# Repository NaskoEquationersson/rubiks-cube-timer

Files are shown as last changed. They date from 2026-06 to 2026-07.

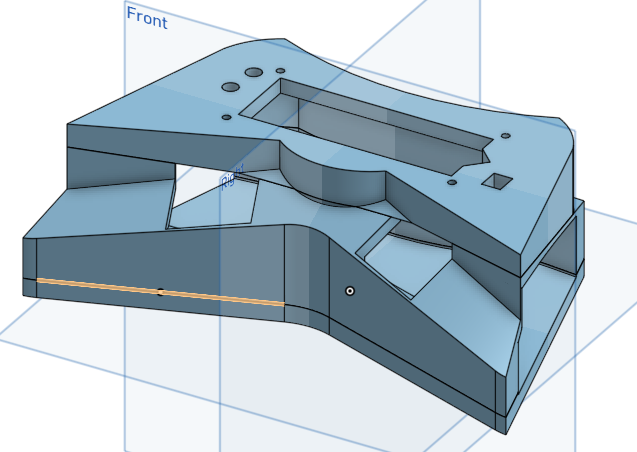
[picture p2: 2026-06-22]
images/Middle.png

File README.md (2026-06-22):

# Nasko's Stasis Rubik's Cube Timer

**Aim**: To make a cheap, reliable timer for my Rubik's Cube runs that includes all the features a standard StackMat provides.

Here is the example circuit design of the project:

newer_circuit

Here is the cover that will be used to contain the Rubik's Cube timer with electronics, without electronics, the Left Hand part, the Right Hand part, and the Middle part:

wElectronics

woElectronics

L

Middle

R

Here is the top case that would be used to communicate with the timer, with and without electronics, from the front and back:

Ekran Görüntüsü 2026-06-22 10-09-04

Ekran Görüntüsü 2026-06-22 10-09-13

Ekran Görüntüsü 2026-06-22 10-28-15

Ekran Görüntüsü 2026-06-22 10-28-27

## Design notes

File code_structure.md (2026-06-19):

# Sections

- Timer Part
- Receiver Display

# Timer Code

Define port numbers.

Define functions that would be used in the code here.

Start

Connect to WiFi, then ESP-NOW.

Define all i/o ports if needed.

Define all variables that would be needed in the code here.

Reset all LEDs to LOW.

While loop to check if the RESET button is not pressed.
Do the RESET function otherwise.

If the RESET button is not pressed, execute the check for the press.

If at least one of the touch sensors are pressed, begin startup sequence.
First set RED_LED to HIGH, then set it LOW, and GREEN_LED to HIGH.
Make sure to do the timing right.

If any point in that code, the reset button is pressed, or no touch sensor is on,
close the loop and close all the lights with the RESET function.

If the sensors are pressed the required time, wait for one of them to be removed, and start the time.

Send this data to the other timer using ESP-NOW.

Wait for all sensors to activate afterwards, after the time starts.
Make sure to accept RESET function anytime.

If all of the sensors are pressed again, stop the time, and send the signal to the remote.

After the time is complete, wait for another entry with either RESET button, or all sensors pressed again.

# Receiver Code

Define port numbers.

Define functions that would be used in the code here.

Start

Connect to WiFi, then ESP-NOW.

Define all i/o ports if needed.

Define all variables that would be needed in the code here.

Receive the data from the other ESP32 via ESP-NOW, and write it on the LCD screen.

If RESET signal comes, empty the LCD.

If FINISH signal comes, open and close the LCD with the time.

Do all of these in a while loop.

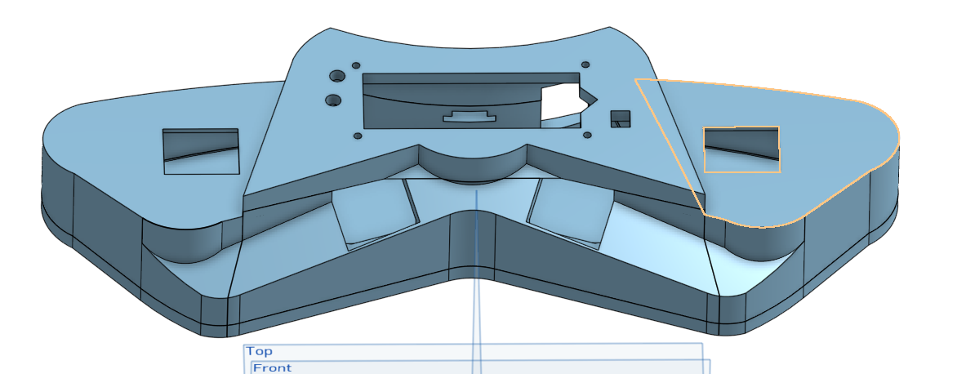
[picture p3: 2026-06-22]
images/woElectronics.png

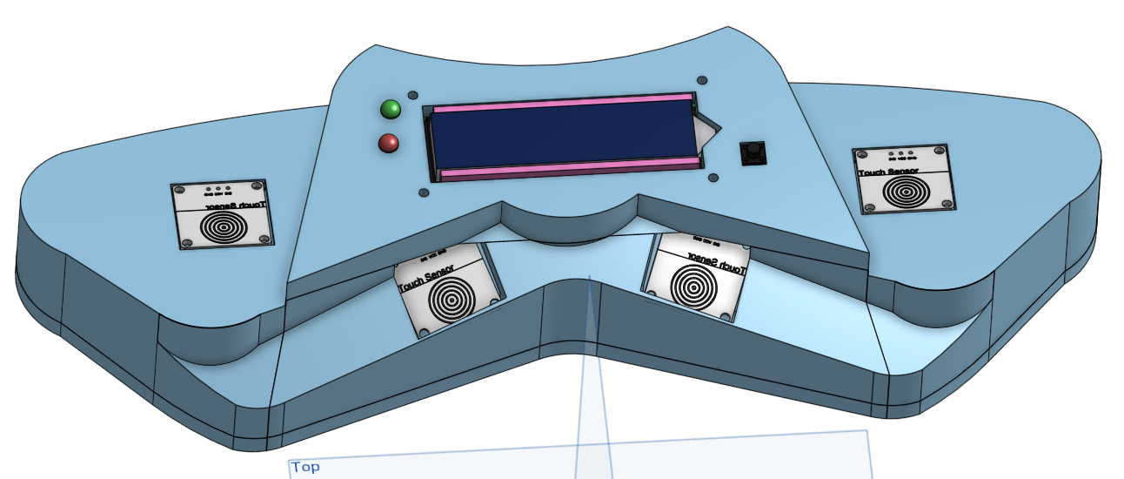
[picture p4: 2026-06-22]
images/wElectronics.png

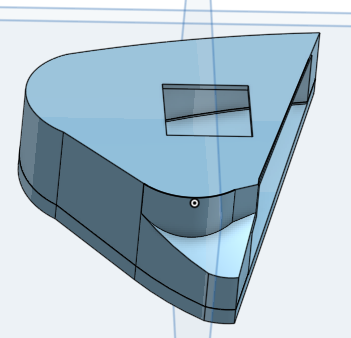
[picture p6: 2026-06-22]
images/L.png

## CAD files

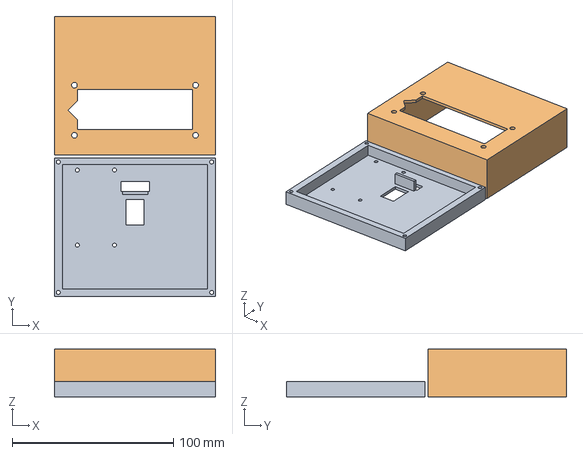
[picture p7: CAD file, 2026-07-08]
final_models/Top_Case.step
100.0 x 173.4 x 29.5 mm

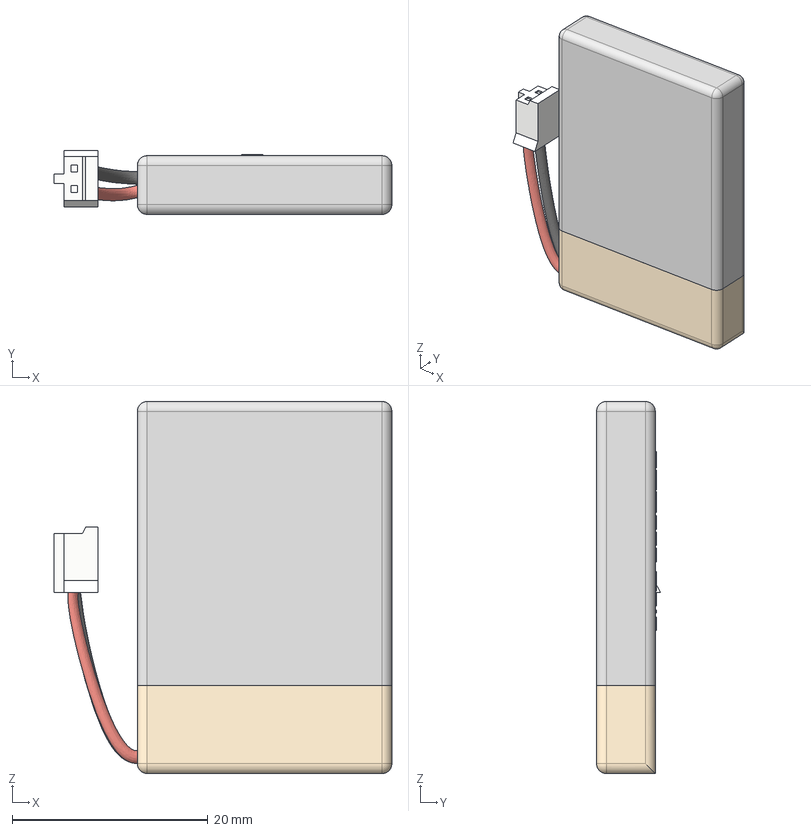
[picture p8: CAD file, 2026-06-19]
models_used_for_scale/3-7v-500mah-lipo-battery-1.snapshot.1/3.3V 500Mah Battery v2.step
34.5 x 6.52 x 38.0 mm
Black wIRE
Red Wire
Connector
Text
Text (1)

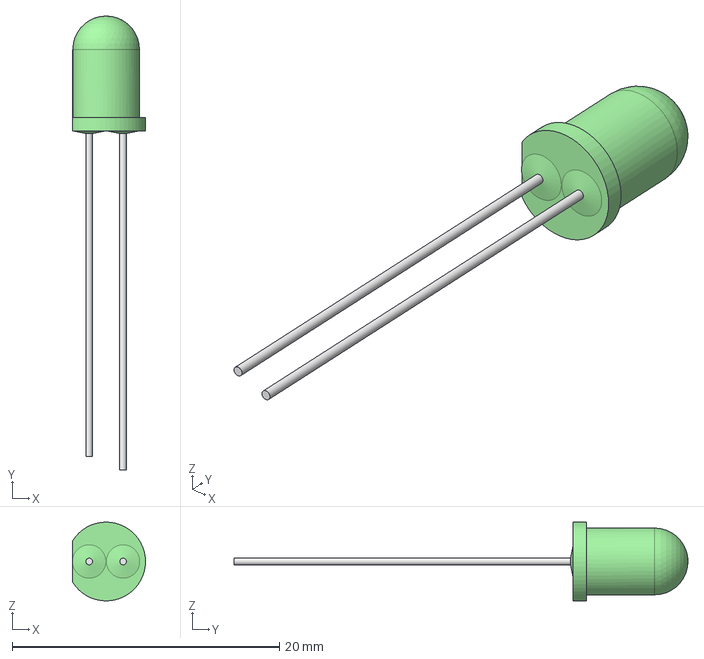
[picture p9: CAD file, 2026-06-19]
models_used_for_scale/5mm-led-green-1.snapshot.1/5mm_LED_Green-0.stp
5.47 x 34.0 x 5.90 mm

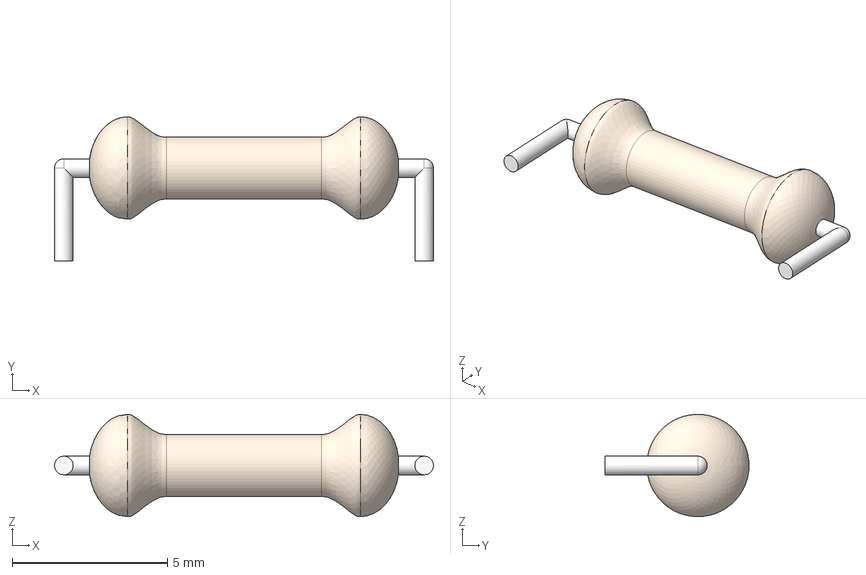
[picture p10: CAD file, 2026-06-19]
models_used_for_scale/generic-1-2w-axial-resistor-1.snapshot.1/1_2W_Axial_res.step
12.2 x 4.65 x 3.30 mm

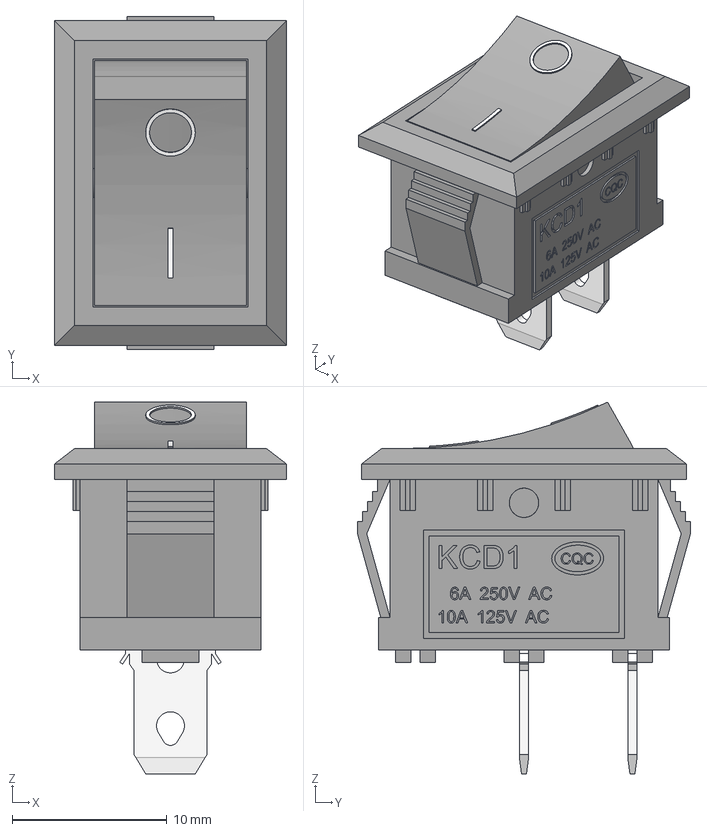
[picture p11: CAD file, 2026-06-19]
models_used_for_scale/kcd1-on-off-rocker-switch-2-pins-1.snapshot.5/kcd1_a.step
15.0 x 21.5 x 24.0 mm
Blade_001
Blade_002
Base_w_text
knob001

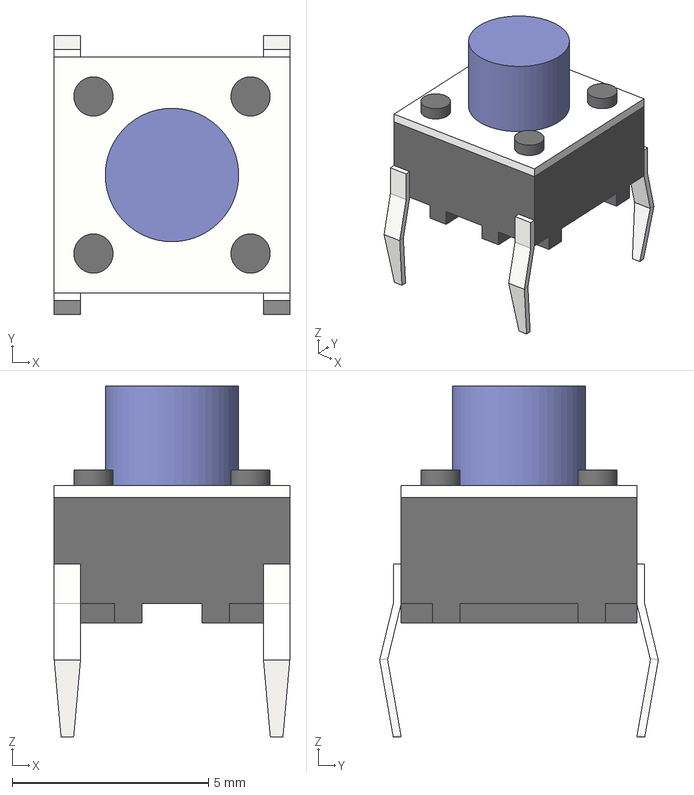
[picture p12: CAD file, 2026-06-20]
models_used_for_scale/micro-momentary-tactile-tact-touch-push-button-switch-6x6x6-mm-1.snapshot.4/Micro Momentary Tactile Tact Touch Push Button Switch, 6x6x6 mm.step
6.00 x 7.10 x 8.94 mm

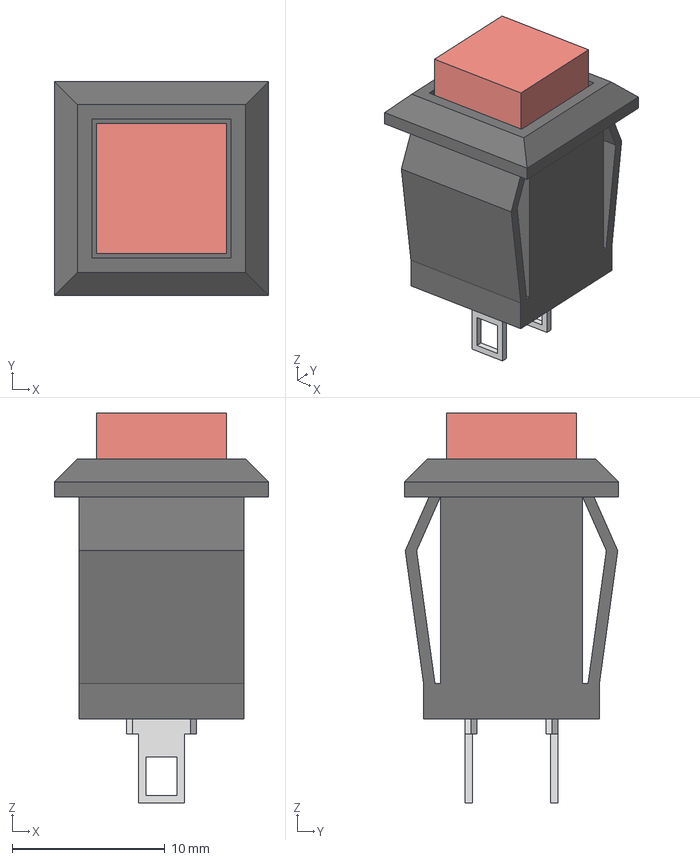
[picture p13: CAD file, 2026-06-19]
models_used_for_scale/square-push-button-ds-431-1.snapshot.13/Square Push Button DS-431 Red.step
14.0 x 14.0 x 25.5 mm

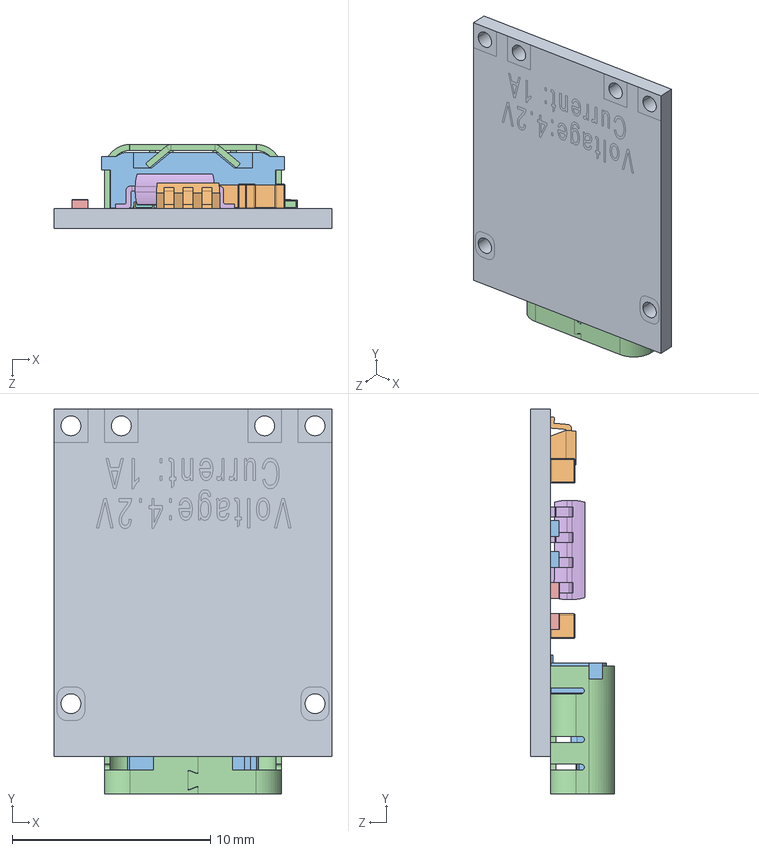
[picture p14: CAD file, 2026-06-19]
models_used_for_scale/tp4056-mini-type-c-battery-charging-module-1.snapshot.1/TP4056 Mini.STEP
14.0 x 19.4 x 4.24 mm

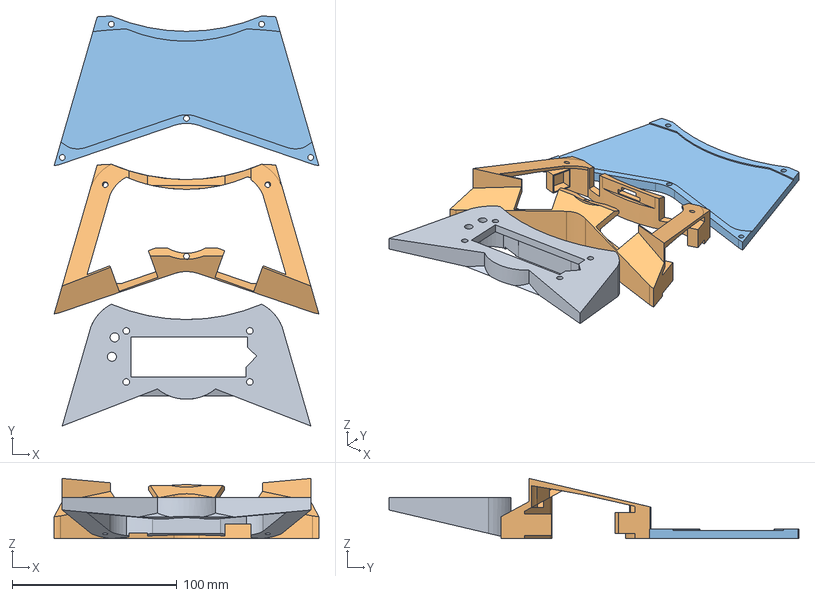
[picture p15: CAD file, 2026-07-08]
final_models/Base.step
160.8 x 249.0 x 36.6 mm

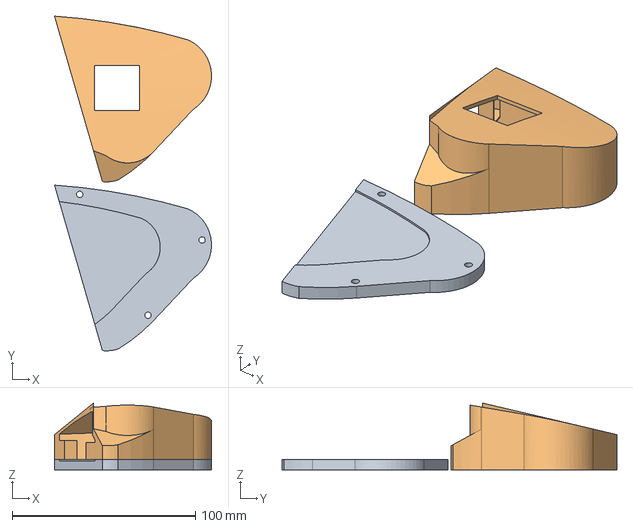
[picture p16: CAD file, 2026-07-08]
final_models/R Hand.step
85.7 x 182.8 x 36.6 mm

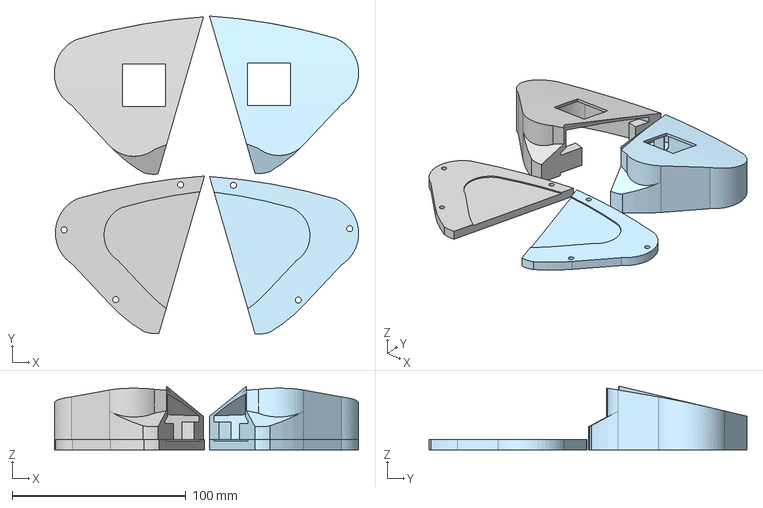
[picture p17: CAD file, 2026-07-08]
final_models/R and L.step
175.0 x 182.8 x 36.6 mm

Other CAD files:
models_used_for_scale/5mm-led-red-2.snapshot.1/5mm_LED_Red-0.stp
models_used_for_scale/square-push-button-ds-431-1.snapshot.13/Square Push Button DS-431 Blue.step
models_used_for_scale/square-push-button-ds-431-1.snapshot.13/Square Push Button DS-431 Black.step
final_models/L Hand.step
models_used_for_scale/square-push-button-ds-431-1.snapshot.13/Square Push Button DS-431 White.step
models_used_for_scale/square-push-button-ds-431-1.snapshot.13/Square Push Button DS-431 Yellow.step
models_used_for_scale/square-push-button-ds-431-1.snapshot.13/Square Push Button DS 431 Green.step
final_models/Base.3mf
final_models/Base.stl
final_models/L Hand.3mf
final_models/L Hand.stl
final_models/R Hand.3mf
final_models/R Hand.stl
final_models/R and L.3mf
final_models/R and L.stl
final_models/Top_Case.3mf
final_models/Top_Case.stl
models_used_for_scale/5mm-led-green-1.snapshot.1/5mm_LED_Green.ipt
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

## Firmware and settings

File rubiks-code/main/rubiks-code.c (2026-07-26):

/*
 * ESP-IDF skeleton: HD44780 parallel LCD + TTP223 touch sensor + ESP-NOW
 *
 * Pin mapping matches your Arduino LiquidCrystal setup:
 *   RS -> GPIO 19
 *   E  -> GPIO 23
 *   D4 -> GPIO 18
 *   D5 -> GPIO 17
 *   D6 -> GPIO 16
 *   D7 -> GPIO 15
 *   RW -> GND (tied directly, not driven from ESP32)
 *   Sensor OUT -> GPIO 27
 *
 * IMPORTANT: Replace `peerAddress[]` below with the actual MAC address
 * of the other ESP32 you're sending to. Print your own board's MAC
 * (see mac_print() below) and hardcode it on the *other* device.
 */

#include <string.h>
#include "freertos/FreeRTOS.h"
#include "freertos/task.h"
#include "driver/gpio.h"
#include "esp_rom_sys.h"   // esp_rom_delay_us
#include "esp_now.h"
#include "esp_wifi.h"
#include "esp_event.h"
#include "esp_netif.h"
#include "esp_log.h"
#include "nvs_flash.h"
#include "esp_timer.h"

static const char *TAG = "APP";

/* ---------------- LCD pin definitions ---------------- */
#define LCD_RS  GPIO_NUM_19
#define LCD_EN  GPIO_NUM_23
#define LCD_D4  GPIO_NUM_18
#define LCD_D5  GPIO_NUM_17
#define LCD_D6  GPIO_NUM_16
#define LCD_D7  GPIO_NUM_15

/* ---------------- Sensor pin ---------------- */
#define SENSOR_1_GPIO GPIO_NUM_27
#define SENSOR_2_GPIO GPIO_NUM_14
#define SENSOR_3_GPIO GPIO_NUM_12
#define SENSOR_4_GPIO GPIO_NUM_13

/* ---------------- LED pins ------------------ */
#define GREEN_LED_GPIO GPIO_NUM_25
#define RED_LED_GPIO GPIO_NUM_32

/* ---------------- Reset Button -------------- */
#define RESET_BUTTON_GPIO GPIO_NUM_26

/* ---------------- Timer Variables ---------------- */
typedef enum {
    TIMER_IDLE,      // waiting for hands to touch all sensors
    TIMER_READY,      // all sensors touched, waiting for release to start
    TIMER_RUNNING,    // counting, waiting for all-touch again to stop
    TIMER_STOPPED     // finished, showing final time until reset
} timer_state_t;

static timer_state_t timer_state = TIMER_IDLE;
static int64_t start_time = 0;
static int64_t stopped_elapsed = 0;
static int prev_all_touched = 0; // for edge detection

/* ---------------- ESP-NOW peer MAC (EDIT THIS) ---------------- */
static uint8_t peerAddress[6] = {0xFF, 0xFF, 0xFF, 0xFF, 0xFF, 0xFF};

typedef struct {
    char text[16];       // e.g. "TurkNasko" or status label
    char time_str[16];   // pre-formatted "00:12.345"
} struct_message;

static struct_message myData;

/* =========================================================
 *                    HD44780 4-bit driver
 * ========================================================= */

static void lcd_pulse_enable(void) {
    gpio_set_level(LCD_EN, 1);
    esp_rom_delay_us(1);
    gpio_set_level(LCD_EN, 0);
    esp_rom_delay_us(100); // most commands need >37us, some need more
}

static void lcd_write4bits(uint8_t nibble) {
    gpio_set_level(LCD_D4, (nibble >> 0) & 0x01);
    gpio_set_level(LCD_D5, (nibble >> 1) & 0x01);
    gpio_set_level(LCD_D6, (nibble >> 2) & 0x01);
    gpio_set_level(LCD_D7, (nibble >> 3) & 0x01);
    lcd_pulse_enable();
}

static void lcd_send(uint8_t value, int mode /* 0 = command, 1 = data */) {
    gpio_set_level(LCD_RS, mode);
    lcd_write4bits(value >> 4);
    lcd_write4bits(value & 0x0F);
}

static void lcd_command(uint8_t cmd) {
    lcd_send(cmd, 0);
}

static void lcd_write_char(char c) {
    lcd_send((uint8_t)c, 1);
}

static void lcd_print(const char *str) {
    while (*str) {
        lcd_write_char(*str++);
    }
}

static void lcd_set_cursor(uint8_t col, uint8_t row) {
    static const uint8_t row_offsets[] = {0x00, 0x40};
    lcd_command(0x80 | (col + row_offsets[row]));
}

static void lcd_clear(void) {
    lcd_command(0x01);
    esp_rom_delay_us(2000); // clear needs ~1.5-2ms
}

static void lcd_gpio_setup(void) {
    gpio_config_t io_conf = {
        .pin_bit_mask = (1ULL << LCD_RS) | (1ULL << LCD_EN) |
                        (1ULL << LCD_D4) | (1ULL << LCD_D5) |
                        (1ULL << LCD_D6) | (1ULL << LCD_D7),
        .mode = GPIO_MODE_OUTPUT,
        .pull_up_en = GPIO_PULLUP_DISABLE,
        .pull_down_en = GPIO_PULLDOWN_DISABLE,
        .intr_type = GPIO_INTR_DISABLE,
    };
    gpio_config(&io_conf);
}

static void lcd_init(void) {
    lcd_gpio_setup();

    // Power-on wait
    vTaskDelay(pdMS_TO_TICKS(50));

    // HD44780 4-bit init sequence (standard datasheet sequence)
    gpio_set_level(LCD_RS, 0);
    lcd_write4bits(0x03);
    vTaskDelay(pdMS_TO_TICKS(5));
    lcd_write4bits(0x03);
    esp_rom_delay_us(150);
    lcd_write4bits(0x03);
    lcd_write4bits(0x02); // set to 4-bit mode

    lcd_command(0x28); // function set: 4-bit, 2 line, 5x8 font
    lcd_command(0x0C); // display on, cursor off, blink off
    lcd_command(0x06); // entry mode: increment, no shift
    lcd_clear();
}

/* =========================================================
 *                    Sensor
 * ========================================================= */

static void sensor_init(void) {
    gpio_reset_pin(SENSOR_1_GPIO);
    gpio_set_direction(SENSOR_1_GPIO, GPIO_MODE_INPUT);
    gpio_reset_pin(SENSOR_2_GPIO);
    gpio_set_direction(SENSOR_2_GPIO, GPIO_MODE_INPUT);
    gpio_reset_pin(SENSOR_3_GPIO);
    gpio_set_direction(SENSOR_3_GPIO, GPIO_MODE_INPUT);
    gpio_reset_pin(SENSOR_4_GPIO);
    gpio_set_direction(SENSOR_4_GPIO, GPIO_MODE_INPUT);
}

static void led_init(void) {
    gpio_reset_pin(GREEN_LED_GPIO);
    gpio_set_direction(GREEN_LED_GPIO, GPIO_MODE_OUTPUT);
    gpio_reset_pin(RED_LED_GPIO);
    gpio_set_direction(RED_LED_GPIO, GPIO_MODE_OUTPUT);
}

static void reset_button_init(void) {
    gpio_reset_pin(RESET_BUTTON_GPIO);
    gpio_set_direction(RESET_BUTTON_GPIO, GPIO_MODE_INPUT);
    gpio_set_pull_mode(RESET_BUTTON_GPIO, GPIO_PULLUP_ONLY);
}

/* =========================================================
 *                    Timer
 * ========================================================= */
static void format_time(int64_t elapsed_us, char *buf, size_t buf_len) {
    int64_t elapsed_ms = elapsed_us / 1000;
    int minutes = (elapsed_ms / 1000) / 60;
    int seconds = (elapsed_ms / 1000) % 60;
    int millis  = elapsed_ms % 1000;
    snprintf(buf, buf_len, "%02d:%02d.%03d", minutes, seconds, millis);
}

void update_timer(int all_touched, int reset_pressed) {
    if (reset_pressed) {
        timer_state = TIMER_IDLE;
        prev_all_touched = 0;
        return;
    }

    int rising_edge  = (all_touched && !prev_all_touched);  // just became fully touched
    int falling_edge = (!all_touched && prev_all_touched);  // just released
    prev_all_touched = all_touched;

    switch (timer_state) {
        case TIMER_IDLE:
            if (rising_edge) {
                timer_state = TIMER_READY; // all touched, now wait for release
            }
            break;

        case TIMER_READY:
            if (falling_edge) {
                start_time = esp_timer_get_time();
                timer_state = TIMER_RUNNING; // released -> start counting
            }
            break;

        case TIMER_RUNNING:
            if (rising_edge) { // touched all again -> stop
                stopped_elapsed = esp_timer_get_time() - start_time;
                timer_state = TIMER_STOPPED;
            }
            break;

        case TIMER_STOPPED:
            // do nothing until reset
            break;
    }
}

/* =========================================================
 *                    ESP-NOW
 * ========================================================= */

static void mac_print(void) {
    uint8_t mac[6];
    esp_wifi_get_mac(WIFI_IF_STA, mac);
    ESP_LOGI(TAG, "My MAC: %02X:%02X:%02X:%02X:%02X:%02X",
             mac[0], mac[1], mac[2], mac[3], mac[4], mac[5]);
}

static void on_data_sent(const esp_now_send_info_t *tx_info, esp_now_send_status_t status) {
    ESP_LOGI(TAG, "Send status: %s",
             status == ESP_NOW_SEND_SUCCESS ? "Success" : "Fail");
}

static void on_data_recv(const esp_now_recv_info_t *info, const uint8_t *data, int len) {
    struct_message incoming;
    if (len != sizeof(incoming)) {
        ESP_LOGW(TAG, "Unexpected data length: %d", len);
        return;
    }
    memcpy(&incoming, data, sizeof(incoming));
    ESP_LOGI(TAG, "Received text: %s", incoming.text);
    ESP_LOGI(TAG, "Received time_str: %s", incoming.time_str);

    // Reflect received value on our own LCD too, if desired:
    lcd_set_cursor(0, 1);
    lcd_print("RX: ");
    lcd_print(incoming.time_str);
}

static void wifi_init(void) {
    ESP_ERROR_CHECK(nvs_flash_init());
    ESP_ERROR_CHECK(esp_netif_init());
    ESP_ERROR_CHECK(esp_event_loop_create_default());

    wifi_init_config_t cfg = WIFI_INIT_CONFIG_DEFAULT();
    ESP_ERROR_CHECK(esp_wifi_init(&cfg));
    ESP_ERROR_CHECK(esp_wifi_set_mode(WIFI_MODE_STA));
    ESP_ERROR_CHECK(esp_wifi_start());
}

static void espnow_init(void) {
    ESP_ERROR_CHECK(esp_now_init());
    ESP_ERROR_CHECK(esp_now_register_send_cb(on_data_sent));
    ESP_ERROR_CHECK(esp_now_register_recv_cb(on_data_recv));

    esp_now_peer_info_t peerInfo = {0};
    memcpy(peerInfo.peer_addr, peerAddress, 6);
    peerInfo.channel = 0;
    peerInfo.encrypt = false;

    if (esp_now_add_peer(&peerInfo) != ESP_OK) {
        ESP_LOGE(TAG, "Failed to add ESP-NOW peer");
    }
}

/* =========================================================
 *                    Main loop / app_main
 * ========================================================= */

void app_main(void) {
    wifi_init();
    mac_print();       // check the Serial/log output to get this board's MAC
    espnow_init();

    sensor_init();
    led_init();
    reset_button_init();
    lcd_init();
    lcd_print("TurkNasko");

    while (1) {
        int state = (gpio_get_level(SENSOR_1_GPIO) && gpio_get_level(SENSOR_2_GPIO) && gpio_get_level(SENSOR_3_GPIO) && gpio_get_level(SENSOR_4_GPIO));

        int reset_pressed = (gpio_get_level(RESET_BUTTON_GPIO) == 0);

        update_timer(state, reset_pressed);

        char timebuf[16];
        int64_t display_elapsed;

        if (timer_state == TIMER_RUNNING) {
            display_elapsed = esp_timer_get_time() - start_time;
        } else if (timer_state == TIMER_STOPPED) {
            display_elapsed = stopped_elapsed;
        } else {
            display_elapsed = 0;
        }

        format_time(display_elapsed, timebuf, sizeof(timebuf));


        // Update local LCD
        lcd_set_cursor(0, 1);
        lcd_print(timebuf);
        lcd_print("     "); // pad to clear leftover chars from longer previous strings

        /*
        Old code to display touch state on the LCD.
        lcd_set_cursor(0, 1);
        lcd_print("Touch: ");
        lcd_write_char(state ? '1' : '0');
        lcd_print(" ");
        */

        // Update LEDs
        gpio_set_level(GREEN_LED_GPIO, state);
        gpio_set_level(RED_LED_GPIO, !state);


        // Populate the struct to send
        strcpy(myData.time_str, timebuf);
        strcpy(myData.text, "TurkNasko");

        // Send over ESP-NOW
        esp_err_t result = esp_now_send(peerAddress, (uint8_t *)&myData, sizeof(myData));
        if (result != ESP_OK) {
            ESP_LOGW(TAG, "esp_now_send failed: %s", esp_err_to_name(result));
        }
        
        vTaskDelay(pdMS_TO_TICKS(50));
    }
}

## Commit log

2026-06-19 Uploaded updated circuit design.
2026-06-19 Updated circuit image.
2026-06-19 Models added to import to Onshape
    [1_2W_Axial_res.obj, 1_2W_Axial_res.sldprt, 1_2W_Axial_res.step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]
2026-06-20 Updated sources after some design
    [Micro Momentary Tactile Tact Touch Push Button Switch, 6x6x6 mm.step, Micro Momentary Tactile Tact Touch Push Button Switch, 6x6x6 mm.stl]
2026-06-21 Uploaded final models for the timer.
    [Base.3mf, Base.step, Base.stl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]
2026-06-22 Uploaded top case's printing files.
    [Top_Case.3mf, Top_Case.step, Top_Case.stl]
2026-06-22 Code added concerning the firmware need for design submission. Plans are made to write the code on build stage.
2026-07-08 Corrected the design.
    [Base.3mf, Base.step, Base.stl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]
2026-07-08 Trying to rebase.
    [R_Hand.3mf, R_Hand.step, R_Hand.stl]
2026-07-08 Fixing the model files not being uploaded to GitHub.
    [R_Hand.3mf, R_Hand.step, R_Hand.stl]
2026-07-11 Started ESP32 code via ESP-IDF.
2026-07-11 Updated code to add LEDs, more sensors, and a timing mechanism.
2026-07-11 Added reset functionality to the circuit.
    [rubiks-code.c]
2026-07-25 Flashed ESP32-Bottom
2026-07-26 Added code for the top esp32.
2026-09-12 Added a method to learn MAC adresses of the ESP32s, fixed earlier code to make ESP-NOW connection work, and moved Sensor 3's GPIO Pin number from 12 to 34 while troubleshooting for boot problems.
2026-10-22 Added a new set of models for manual wiring option.
